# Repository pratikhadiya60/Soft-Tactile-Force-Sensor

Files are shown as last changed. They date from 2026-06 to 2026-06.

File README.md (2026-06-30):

# Soft Tactile Force Sensor

<p align="center">
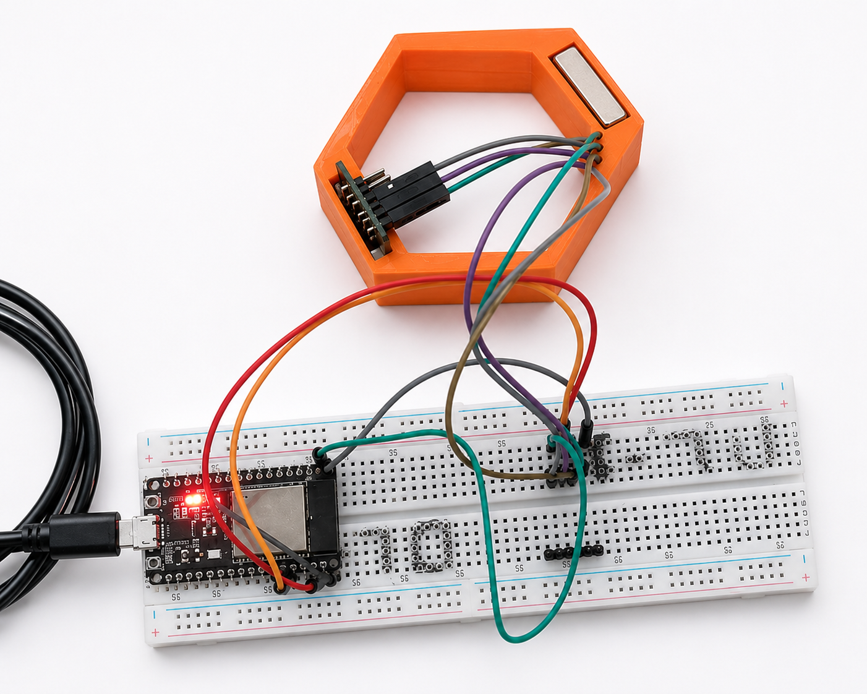
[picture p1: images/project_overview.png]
Prototype Setup
  
</p>

A soft tactile force sensor built using an ESP32 and an MLX90393 magnetometer. The sensor estimates contact force by tracking the movement of a small embedded magnet inside a silicone structure and sends the measurements to a local Flask server over Wi-Fi.

## About the Project

The idea for this project was to estimate contact force without using a traditional load cell.

A small magnet is embedded inside a soft silicone structure while an MLX90393 magnetometer is fixed below it. Whenever force is applied, the silicone compresses and the magnet moves closer to the sensor. This changes the measured magnetic field.

The ESP32 continuously reads the magnetic field values, estimates how much the magnet has moved, and converts that displacement into force using calibration data collected from compression tests. The calculated force is then sent over Wi-Fi to a Flask server where it can be monitored in real time.

This project combines mechanical design, embedded programming, experimental calibration, and basic web-based visualization into a single tactile sensing system.

## How It Works

The sensing principle is fairly simple. Instead of measuring force directly, the sensor measures how much the silicone deforms under an external load.

When force is applied to the top surface, the silicone compresses and the embedded magnet moves closer to the MLX90393 magnetometer. Since the magnetic field strength increases as the distance decreases, the ESP32 can estimate the displacement by monitoring the magnetic field.

The estimated displacement is then converted into force using calibration data collected from compression tests. Finally, the calculated force is sent to a local Flask server where it can be displayed in real time.

## Project Highlights

- Soft silicone based tactile sensing approach
- ESP32 firmware developed using PlatformIO
- MLX90393 3-axis magnetometer for magnetic field measurement
- Experimental force calibration using compression test data
- Real-time force estimation
- Wi-Fi communication with a Flask server
- Complete CAD models, firmware, documentation and calibration data included in this repository

<p align="center">
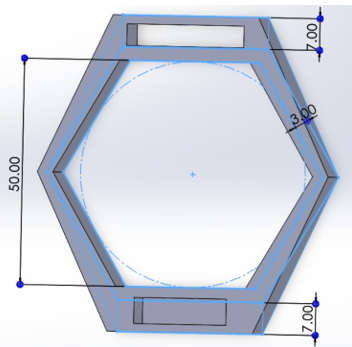
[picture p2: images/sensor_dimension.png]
  
</p>

### Measurement Pipeline

```text
Applied Force
      │
      ▼
Silicone Deformation
      │
      ▼
Magnet Displacement
      │
      ▼
MLX90393 Magnetic Field Measurement
      │
      ▼
ESP32 Processing
      │
      ▼
Displacement Estimation
      │
      ▼
Force Calculation
      │
      ▼
Wi-Fi Data Transmission
      │
      ▼
Flask Server
```

### Force Estimation

The firmware first calibrates the MLX90393 to remove sensor offsets and compensate for the Earth's magnetic field. Once calibration is complete, the magnetic field magnitude is used to estimate the distance between the magnet and the sensor.

The displacement is calculated with respect to the reference position, and a lookup table obtained from experimental testing is used to estimate the corresponding force. Linear interpolation is used between calibration points to improve the resolution of the measurement.

## Repository Structure

The repository is organized so that each part of the project is kept separate. Firmware, CAD files, experimental data, documentation, and hardware files can all be accessed independently.

```text
Soft-Tactile-Force-Sensor
│
├── firmware/      ESP32 firmware (PlatformIO)
├── hardware/      Circuit diagram
├── cad/           3D models of the sensor housing
├── data/          Experimental calibration data
├── docs/          Project report
├── images/        Figures used in this README
├── media/         Project photos and videos
└── server/        Flask server for data visualization
```

## Hardware Used

The prototype was built using commonly available components.

| Component | Description |
|---|---|
| ESP32 DevKit V1 | Main controller |
| MLX90393 | 3-axis magnetometer |
| Neodymium Magnet | Embedded inside the silicone sensor |
| Silicone Structure | Deforms under external force |
| 3D Printed Housing | Holds the sensor and electronics together |

## Circuit Diagram

The ESP32 communicates with the MLX90393 over the I²C interface.

<p align="center">
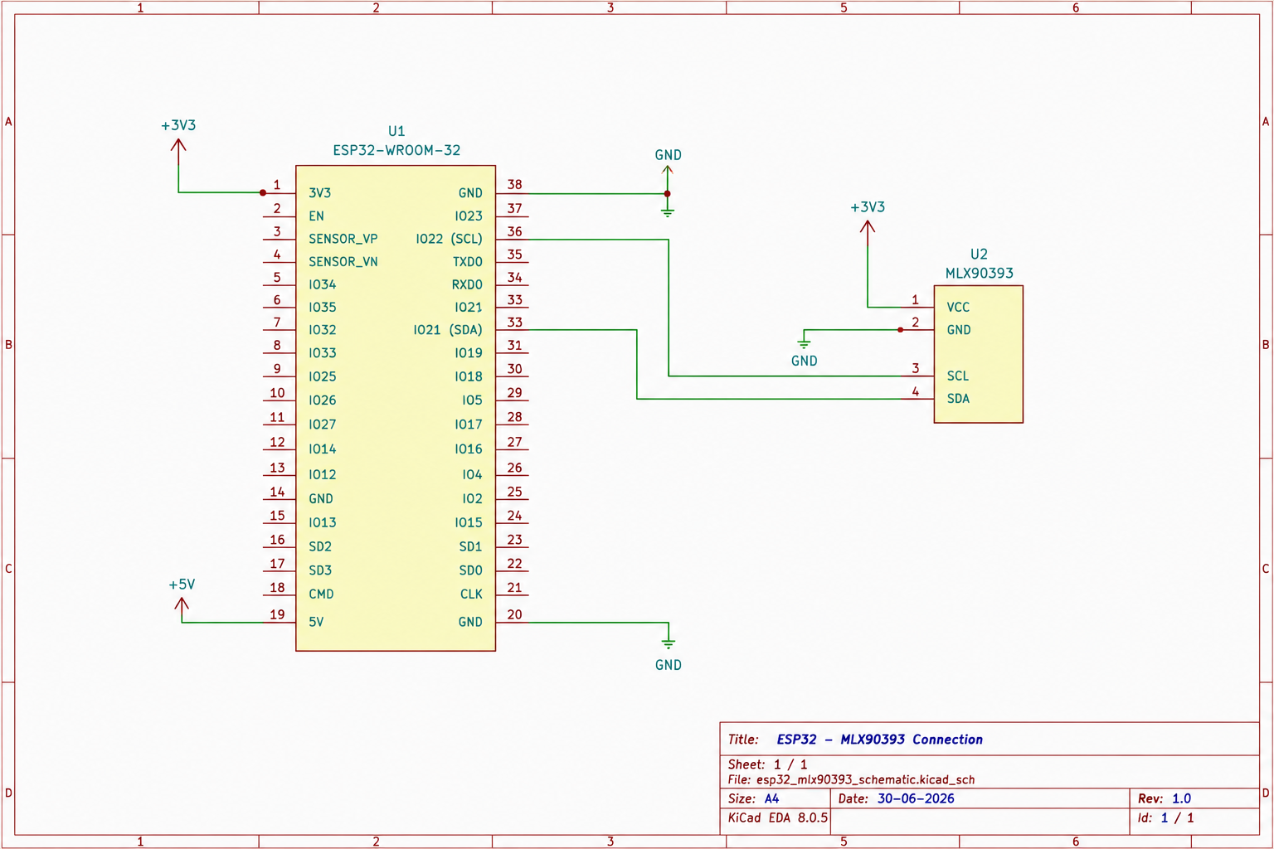
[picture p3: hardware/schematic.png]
  
</p>

| ESP32 | MLX90393 |
|---|---|
| 3.3V | VIN |
| GND | GND |
| GPIO21 | SDA |
| GPIO22 | SCL |

The DRDY and INT pins of the MLX90393 are not used in this project.

## Software

Different parts of the project were developed using different tools.

| Software | Purpose |
|---|---|
| PlatformIO | ESP32 firmware development |
| VS Code | Programming |
| SolidWorks | CAD design |
| COMSOL Multiphysics | Magnetic field simulation |
| Flask | Local server |
| Python | Data visualization |

# Results

The sensor was tested at different stages of development to verify the sensing principle and generate the calibration data used by the firmware.

Instead of estimating force directly from the magnetic field, the system first estimates the displacement of the embedded magnet and then converts that displacement into force using experimentally collected data.

## Magnetic Field vs Distance

The first experiment was performed to study how the magnetic field changes as the distance between the magnet and the MLX90393 sensor changes.

<p align="center">
  
</p>

As expected, the magnetic field increases rapidly when the magnet moves closer to the sensor. This relationship is used by the firmware to estimate the displacement of the magnet during force measurement.

## Magnetic Field Simulation

To better understand the magnetic field distribution around the magnet, a simple COMSOL simulation was performed.

<p align="center">
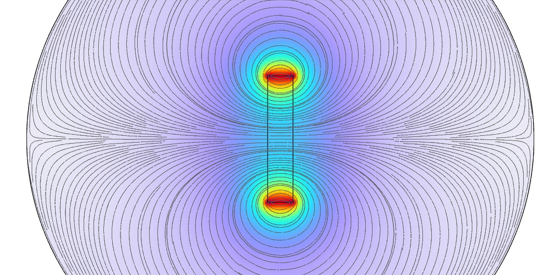
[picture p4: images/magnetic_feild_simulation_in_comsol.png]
  
</p>

The simulation helped visualize the magnetic field around the magnet and confirmed the expected field distribution before building the prototype.

## Compression Test

Compression testing was carried out to obtain the force-displacement data required for calibration.

<p align="center">
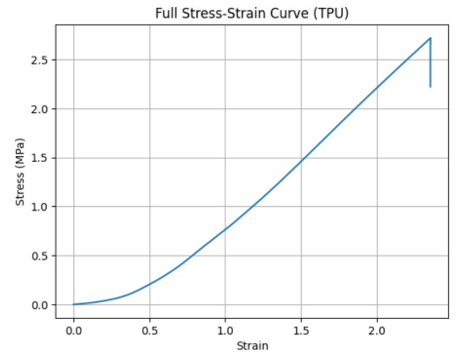
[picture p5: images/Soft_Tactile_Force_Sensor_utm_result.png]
  
</p>

The experimental data obtained from these tests was later converted into a lookup table that is used by the ESP32 firmware for force estimation.

## Force Calibration

The lookup table generated from the compression test is used to convert displacement into force.

<p align="center">
  
</p>

Instead of fitting a mathematical equation, the firmware performs linear interpolation between calibration points. This keeps the implementation simple while closely matching the experimental data.

## Prototype

The final prototype consists of the ESP32 development board, the MLX90393 sensor module, and the 3D printed housing that holds the sensing element.The ESP32 continuously measures the magnetic field, estimates the force, and sends the calculated values to the Flask server over Wi-Fi.

# Getting Started

## Clone the Repository

```bash
git clone https://github.com/pratikhadiya60/Soft-Tactile-Force-Sensor.git
cd Soft-Tactile-Force-Sensor
```

## Firmware

The firmware is developed using **PlatformIO**.

Open the `firmware` folder in VS Code with the PlatformIO extension installed.

Build the project:

```bash
PlatformIO → Build
```

Connect the ESP32 and upload the firmware:

```bash
PlatformIO → Upload
```

Before uploading, update the Wi-Fi credentials and the server IP address in `src/main.cpp`.

## Running the Flask Server

The ESP32 sends force measurements to a local Flask server over Wi-Fi.

Move to the `server` directory and install the required Python packages.

```bash
cd server
pip install -r requirements.txt
python app.py
```

Once the server is running and the ESP32 is connected to the same network, the measured force values will be transmitted automatically.

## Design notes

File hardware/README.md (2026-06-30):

# Hardware

Contains the circuit diagram and hardware documentation.

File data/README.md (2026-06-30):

# Experimental Data

This folder contains the raw experimental datasets used for calibration and validation.

- TPU tensile test
- Compression test
- Force-displacement measurements

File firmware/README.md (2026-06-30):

# Firmware

This folder contains the ESP32 firmware for the Soft Tactile Force Sensor.

## Hardware

- ESP32 DevKit V1
- MLX90393 3-axis magnetometer

## Framework

- PlatformIO
- Arduino Framework

## Libraries

- Adafruit MLX90393 Library

## Build

Open the `firmware` folder in VS Code with PlatformIO and click **Build**.

## Upload

Connect the ESP32 and click **Upload** in PlatformIO.

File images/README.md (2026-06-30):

# Images

This folder contains figures used in the documentation.

- Sensor setup
- Circuit diagram
- COMSOL simulation
- Calibration graph
- UTM results

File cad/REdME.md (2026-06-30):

# CAD Files

This folder contains the CAD model of the magnetometer holder.

Files included:

- `.SLDPRT` - SolidWorks Part
- `.STEP` - Universal CAD model
- `.STL` - 3D printable model

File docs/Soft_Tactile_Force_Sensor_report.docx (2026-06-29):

# Design Lab–1 (ME-205) Project Report

Magnetometer-Based Force Sensing Instrument

Using TPU Hexagonal Structure

Group-C (Section-B)

Team Members:
Hadiya Pratik Ghanshyambhai (2024MEB1347)
Kanav Dumra (2024MEB1356)
Kodepaka Aravind Stalin (2024MEB1361)
Manav Gulati (2024MEB1366)
Pratyush Sahu (2024MEB1373)

Supervised by: Dr. Prabhat K. Agnihotri
LA: Rupinder Singh Mundra
Date: 30 April 2026

Abstract:

This project presents the design and experimental validation of a magnetometer-based force sensing instrument using a flexible hexagonal TPU structure. The system works on the principle that mechanical deformation leads to change in the distance between magnet and magnetometer, which further leads to a change in the magnetic field, which is detected using a magnetometer.

A hexagonal structure was designed and fabricated using Thermoplastic Polyurethane (TPU). A permanent magnet was fixed at one end, while a magnetometer sensor connected to an ESP32 microcontroller was placed at the opposite end. Compression of the structure results in displacement of the magnet, causing measurable variations in magnetic field.

The project involves:

- Calibration of magnetic field vs distance using a Gauss meter
- Measurement of magnetic field variation under deformation
- Mechanical characterization using UTM (Universal Testing Machine)

The results demonstrate a clear relationship between force, deformation, and magnetic field variation, validating the concept of low-cost force sensing.

Introduction:

Force sensing is essential in applications such as robotics, prosthetics, and material testing. Traditional sensors (load cells, strain gauges) can be expensive or rigid. This project explores a flexible and low-cost alternative using:

- Soft material (TPU)
- Magnetic sensing
- Embedded electronics (ESP32)

The working principle is simple:

Applied Force → Deformation → Change in Magnet Distance → Magnetic Field Variation → Electrical Signal

Unlike complex multi-layer metamaterial designs, this project focuses on a single hexagonal unit.

Objectives:

1. To study magnetic field variation with distance To experimentally determine how the magnetic field strength varies with distance from a permanent magnet using a gauss meter, and to establish a calibration curve for further analysis.
2. To simulate magnetic field distribution around a permanent magnet To simulate and analyse the distribution pattern of magnetic field lines around a block magnet
3. To measure magnetic field variation under deformation To analyze how compression of the hexagonal structure affects the distance between the magnet and magnetometer, and to record the resulting changes in magnetic field using an ESP32-based setup.
4. To correlate force, deformation, and magnetic response To develop a relationship between applied force, structural deformation, and corresponding magnetic field variation, thereby demonstrating the working principle of the force sensing mechanism.
5. To validate results using UTM testing To perform mechanical testing using a Universal Testing Machine (UTM) on both a standard TPU specimen and the hexagonal structure.

Theoretical Background:

Force vs Deformation (F–Δx Relationship)

The mechanical behavior of the TPU hexagonal structure can be approximated using Hooke’s Law for elastic materials:

F=k⋅Δx

Where:

- F = Applied force (N)
- k = Effective stiffness of the structure (N/mm)
- Δx = Deformation (mm)

Explanation

- When force is applied, the hexagonal structure compresses
- Initially, the behavior is approximately linear (elastic region)
- The slope of the graph gives stiffness:

k=F/(Δx)

In our Project

- From UTM results:
  - We obtained stress vs strain
  - From that, stiffness can be estimated
- For the hexagon:
  - Stiffness is lower than solid cylinder, which was used earlier for experimentally identifying the Young’s Modulus using ASTM standards.
  - Because of geometric flexibility

Magnetic Field vs Distance

The magnetic field produced by a magnet decreases with distance. For a bar magnet, it approximately follows:

B∝1/(r^n)

Where:

- B = Magnetic field
- r = Distance from magnet
- n≈2 to 3

In our Experiment

- We measured:
  - Magnetic field vs distance (10 cm → 1 cm)
- This serves as calibration data

Magnetic Field vs Deformation (ΔB vs Δx)

When the hexagon compresses:

- Distance decreases:

r=r_0 -Δx

- So the magnetic field becomes:

B=f(r_0 -Δx)

Thus:

ΔB=B(Δx)-B_0

Key Insight

- Small deformation → small increase in B
- Larger deformation → rapid increase in B
- Relationship is non-linear

Force vs Magnetic Field (F–ΔB Relationship)

Combining both relations:

F=k⋅Δx

and

B=f(Δx)

We can write:

F=k⋅f^(-1) (B)

Practical Meaning

- Magnetometer gives magnetic field
- From calibration, we get deformation
- From deformation, we calculate force

Simplified Relation

If small deformation:

ΔB∝Δx

Then:

F∝ΔB

So:

Force is approximately proportional to change in magnetic field (for small deformation range)

COMSOL Simulation:

Simulation of Simple Bar Magnet

Objective

To understand how magnetic field varies with distance from a magnet.

Model Description

- Geometry: Simple bar magnet
- Domain: Air surrounding the magnet
- Physics: Magnetic Fields

Result

- Magnetic field decreases with distance

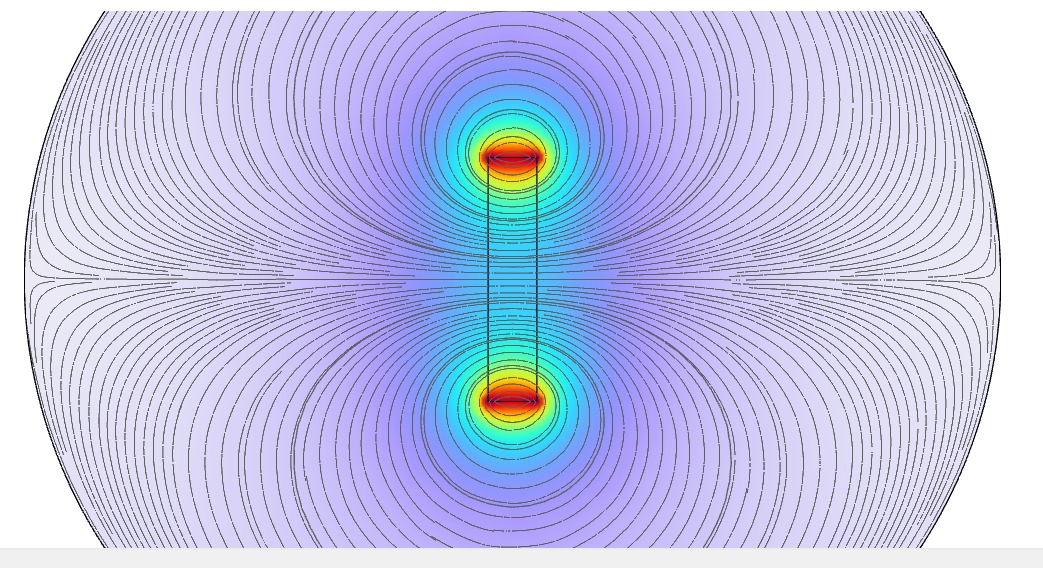
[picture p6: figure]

Conclusion

- Validates the theoretical relation:

B∝1/(r^n)

Working Principle:

The system operates based on the relation between magnetic field and distance.

As the structure compresses:

- Distance between magnet and sensor decreases
- Magnetic field strength increases

This relationship can be approximated as: B∝1/(r^n)

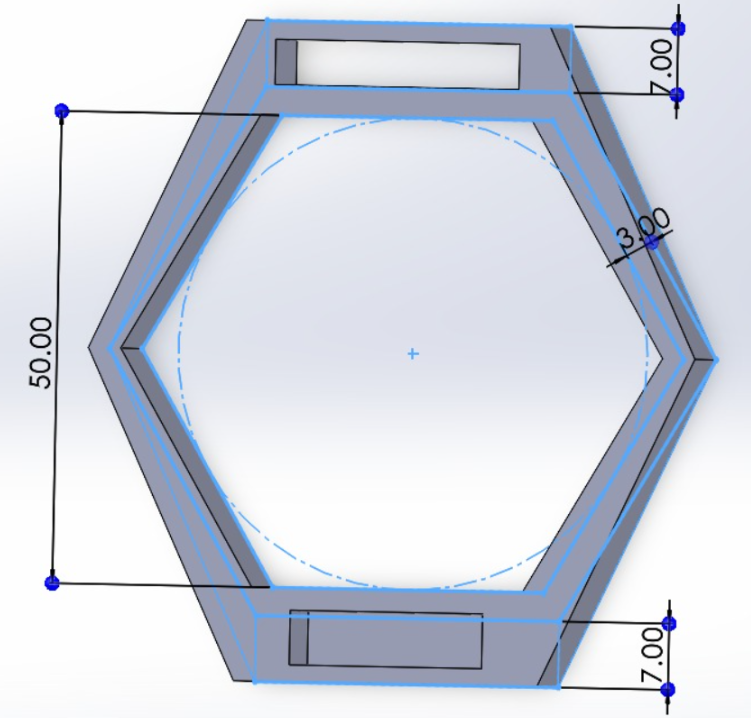
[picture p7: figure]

Design and Fabrication:

CAD Model

- Geometry: Hexagonal structure
- Software used: SolidWorks
- Thickness: 20mm

Material

- Material: Thermoplastic Polyurethane (TPU)
- Properties:
  - Elastic modulus: E≈1.3×10^5 Pa
  - Density: 30 %

Experimental Setup:

Components Used

- Magnetometer: SmartElex MLX90393 Triple Axis Magnetometer (Used to measure the magnetic field variation due to deformation)
- Microcontroller: ESP32 (Used for data acquisition, processing, and real-time output)
- Magnet:
  - Shape: Cubic
  - Size: 1 cm × 1 cm × 1 cm

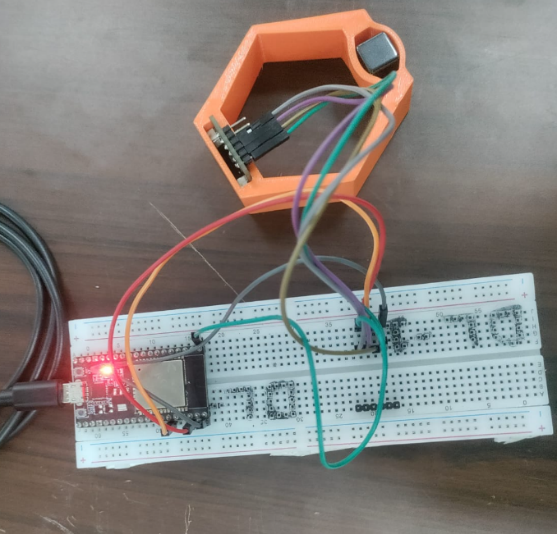
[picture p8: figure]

- Hexagonal Structure:
  - Material: Thermoplastic Polyurethane (TPU)
  - Fabrication method: 3D Printing
- Additional Equipment:
  - Gauss meter (for calibration)
  - Connecting wires and power supply

Setup Description

The experimental setup consists of a flexible hexagonal TPU structure with a magnet and magnetometer placed at opposite ends. The arrangement is designed such that any applied force leads to deformation, which changes the distance between the magnet and the sensor.

- The permanent magnet is rigidly fixed at one end of the hexagonal structure.
- The magnetometer sensor is mounted at the opposite fixed end, ensuring it remains stationary during the experiment.
- The ESP32 microcontroller is connected to the magnetometer to record magnetic field readings in real time and transmit the data to a serial monitor or computer.

Working Configuration

- When no force is applied:
  - The structure remains in its original shape
  - Distance between magnet and sensor is maximum
  - Magnetic field reading is at baseline
- When force is applied:
  - The hexagonal structure compresses
  - Distance between magnet and sensor decreases
  - Magnetic field strength increases

Key Considerations

- Proper alignment of magnet and sensor is maintained to ensure accurate readings
- The structure is compressed along its axis of symmetry
- External disturbances (vibration, misalignment) are minimized

Magnetic Field Calibration:

Objective: To determine the relationship between magnetic field strength and distance from the magnet, which is required for interpreting sensor readings in later experiments.

Procedure

- A Gauss meter was used to measure magnetic field strength.
- The magnet was kept fixed, and the distance between the magnet and probe was varied from 10 cm to 1 cm.
- Readings were recorded at different distances while maintaining proper alignment and minimizing external disturbances.

Observations

Distance (cm) | Magnetic Field (Gauss)
10 cm | 0.1
9 cm | 0.1
8 cm | 0.4
7 cm | 1.0
6 cm | 2.0
5 cm | 4.1
4 cm | 7.7
3 cm | 18.1
2 cm | 52.7
1 cm | 181.2

Result

- The magnetic field increases as the distance decreases.
- The variation is non-linear, with a sharper increase at smaller distances.

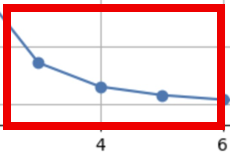
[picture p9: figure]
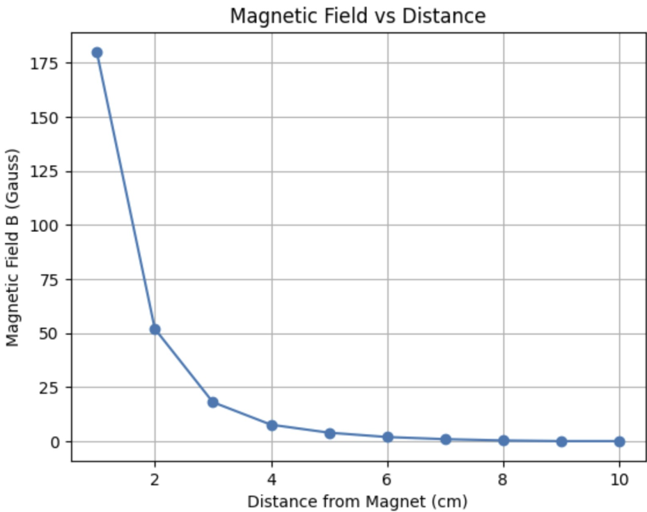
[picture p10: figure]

Compared with the practical graph

Conclusion: The calibration confirms the expected inverse relationship between magnetic field and distance. This serves as a reference for relating magnetic field changes to deformation in the hexagonal structure.

Deformation vs Magnetic Field Experiment:

Objective

To study how mechanical deformation of the hexagonal structure affects the magnetic field, and to establish a relationship between deformation and magnetic field variation.

Procedure

- The fabricated TPU hexagonal structure was placed in a controlled setup.
- The sensor was calibrated in the absence of the magnet.
- At the undeformed state, four different values of the magnetic field were recorded, and the average value was used as the reference value for the undeformed state.
- Compression was applied gradually.
- As the structure compressed, the distance between the magnet and magnetometer decreased.
- The magnetometer readings were recorded in real time using the ESP32 microcontroller.
- Corresponding values of deformation and magnetic field were noted for multiple loading conditions.

Axis Calibration and Vector Correction in 3-Axis Magnetometer

- Introduction: In a 3-axis magnetometer system, the measured magnetic field components (B_x , B_y , B_z ) are affected not only by the external magnetic field but also by sensor misalignment, scaling errors, and cross-axis coupling. During experimentation, it was observed that even when the magnet is moved along a single axis (e.g., X-direction), all three components change. This behavior arises due to the vector nature of the magnetic dipole field and imperfect alignment between the magnet and sensor axes.
- Need for Axis Calibration: Axis calibration is required to ensure that:
- Each axis responds uniformly to the same magnetic field strength
- Cross-axis interference is minimized
- The measured field accurately represents physical motion of the magnet
- Distance estimation based on magnetic field becomes reliable

Without calibration, the sensor output forms an ellipsoidal distortion instead of a spherical response, leading to inaccurate field interpretation.

- Physical Observation of Cross-Axis Coupling: When a magnet is moved along the X-axis, the expected behavior is that only B_x should vary. However, experimentally:
- B_x , B_y , and B_z all change simultaneously
- This occurs because the magnetic field of a bar magnet follows a 3D dipole distribution
- The field at any point depends on position vector (x, y, z) , not independent axes

Thus, axis separation is not perfect in raw sensor data.

- Mathematical Representation: The magnetic field of a dipole is given by:

B(r)=(μ_0)/(4πR^3)[3(m⋅r)r-m]

This implies that:

- Each component B_x ,B_y ,B_z depends on all spatial coordinates
- Movement in one axis inherently affects all three components
- Practical Axis Calibration Method: Instead of relying on theoretical alignment, an experimental calibration approach is used:

Step 1: Data Collection

- Move the magnet in all directions (3D motion)
- Record raw values:

B_x ,B_y ,B_z

Step 2: Hard Iron Correction

Remove constant offset:

B_(offset) =(B_(max) +B_(min))/2

Step 3: Soft Iron Correction

Normalize scaling differences:

B_(scaled) =(B_(corrected))/(Scale factor)

Step 4: Axis Alignment Approximation

Since perfect rotation matrices are complex for this setup, an effective axis is constructed:

B_(aligned) =aB_x +bB_y +cB_z

where a,b,c are experimentally determined weights based on sensitivity.

- Preferred Practical Approach: For this project, instead of relying on individual axis accuracy, the magnetic field magnitude is used:

∣B∣=√(B_x^2 +B_y^2 +B_z^2)

Advantages:

- Independent of sensor orientation
- Eliminates axis misalignment effects
- Provides stable and smooth response
- Suitable for distance estimation models
- Conclusion: Axis calibration improves the reliability of magnetometer readings by correcting offsets, scaling errors, and misalignment effects. However, due to inherent cross-axis coupling in magnetic dipole fields, complete axis separation is not physically achievable. Therefore, the most robust approach for this project is to use vector magnitude ∣B∣ , which provides orientation-independent and stable measurements suitable for distance estimation and force sensing applications.

Observations

Deformation (mm) | Magnetic Field (Gauss)
59.92 | 3.511
57.98 | 3.8756
54.39 | 4.6947
50.46 | 5.8797
46.40 | 7.5637
41.10 | 1.0879
36.54 | 1.5487
31.39 | 2.4432
29.98 | 2.8042
28.94 | 3.1179

Graphical Representation

A graph was plotted between:

- X-axis: Deformation (mm)
- Y-axis: Magnetic Field

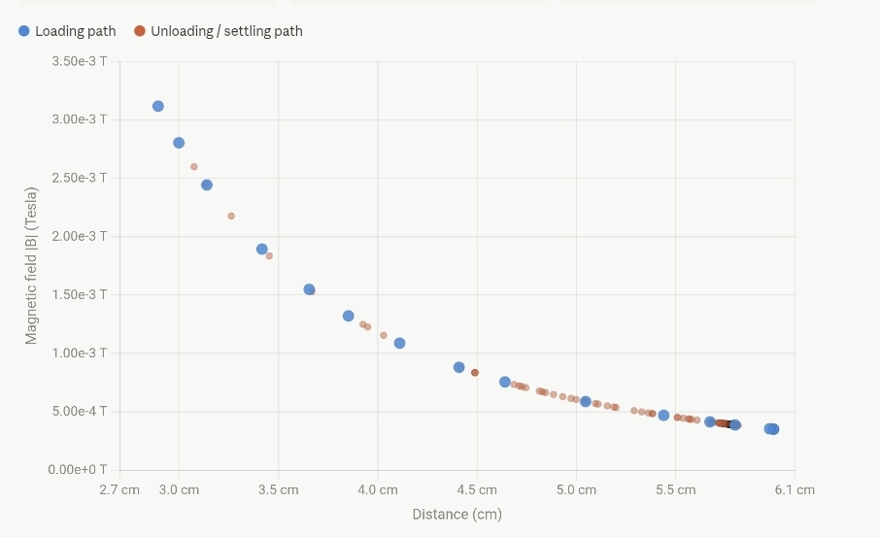
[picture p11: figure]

Results and Analysis

- It was observed that the magnetic field increases with increasing deformation.
- This is because compression reduces the distance between the magnet and sensor.
- The relationship is non-linear, with a steeper increase at higher deformation values.

Key Insight

- Small deformation produces measurable changes in magnetic field
- Sensitivity increases as the magnet comes closer to the sensor

Conclusion

The experiment confirms that deformation of the hexagonal structure leads to a predictable change in magnetic field. This validates the working principle of the system and shows that magnetic field variation can be used to estimate deformation and applied force.

UTM Testing:

Objective: To determine the mechanical properties of TPU material and the hexagonal structure by obtaining their stress–strain behavior, and to relate this behavior to the deformation observed in the force sensing experiment.

TPU Cylindrical Sample

- A standard TPU cylindrical specimen was prepared according to ASTM standards.
- The sample was tested using a Universal Testing Machine (UTM) under compressive loading.

Procedure

- The specimen was placed between the compression plates of the UTM.
- Load was applied gradually, and corresponding deformation was recorded.
- Stress and strain values were calculated from the load and displacement data.

Graph: Stress vs Strain

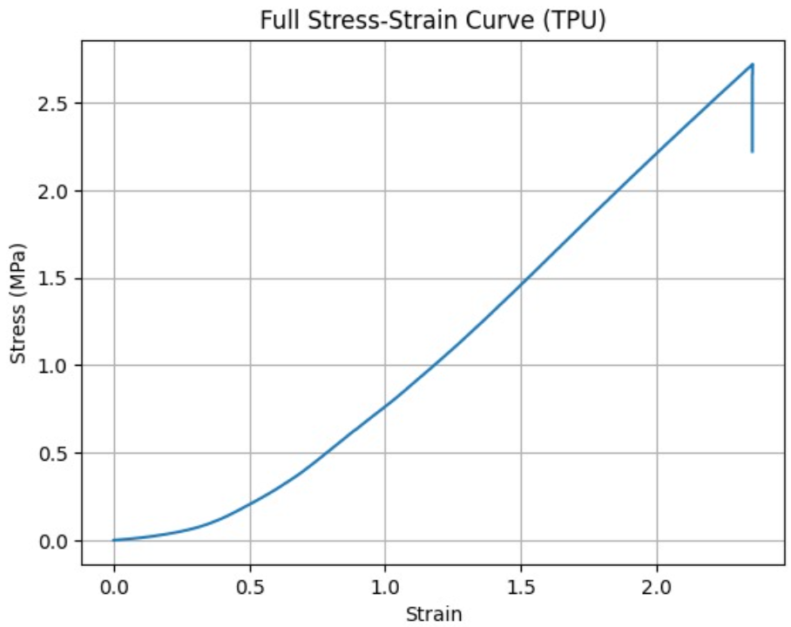
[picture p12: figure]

Young’s Modulus (calculated using the graph): E≈1.3×10^5 Pa

Hexagonal Structure Testing

- The same compression test was performed on the 3D printed hexagonal TPU model.

Procedure

- The hexagonal structure was placed in the UTM.
- Load was applied along its axis of symmetry.
- Deformation and corresponding force were recorded.

Graph:
Force vs Displacement:

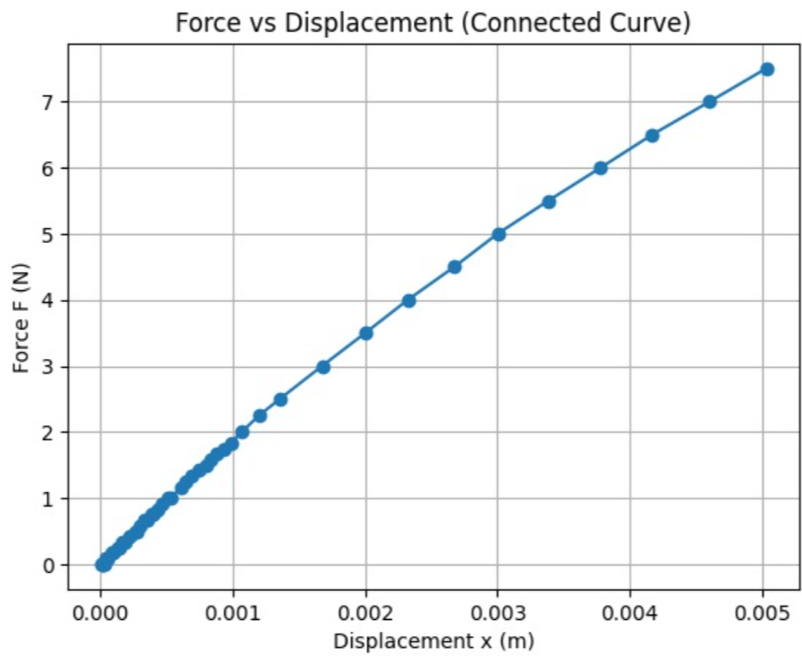
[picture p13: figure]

Stress vs Strain:

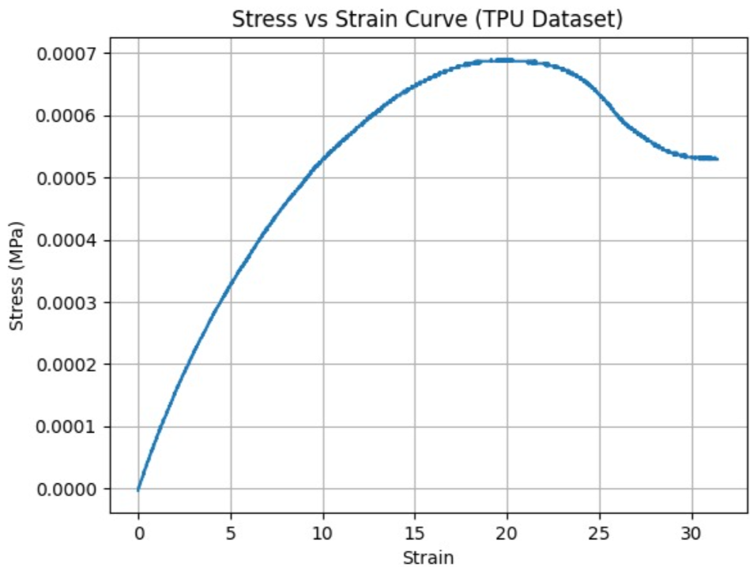
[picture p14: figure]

Equivalent Spring Constant (calculated from the above curve): k≈1500 N.m^(-1)

Results and Comparison

- The TPU cylindrical sample showed a relatively uniform and predictable stress–strain curve, representing the base material behavior.
- The hexagonal structure exhibited:
  - Lower stiffness
  - Higher deformation for the same load
  - Non-linear behavior due to geometry

Key Insight

- The difference in behavior confirms that:

Geometry plays a major role in flexibility and deformation, not just material properties.

Conclusion

UTM testing successfully provided the mechanical characterization of both the material and the structure. The results help in understanding how applied force leads to deformation, which is essential for correlating force with magnetic field variation in the sensing system.

Results and Discussion:

The experimental study provides a clear relationship between mechanical deformation and magnetic field variation. The system demonstrates that even small compressive forces applied to the TPU structure lead to measurable changes in magnetic field intensity.

Magnetic Field vs Distance Behavior

The calibration results confirm that magnetic field strength increases sharply as the distance between magnet and sensor decreases. The observed trend follows a non-linear inverse relationship, consistent with theoretical dipole field behavior.

Key observations:

- Strong sensitivity at small distances (< 5 cm)
- Gradual flattening of response at higher distances

Deformation Response

Under compression, the hexagonal TPU structure behaves elastically within the tested range. The deformation causes a proportional increase in magnetic field reading.

Important findings:

- Initial region shows near-linear response between deformation and magnetic field
- At higher compression, slight non-linearity appears due to geometric instability

Force–Magnetic Coupling

By combining UTM data with sensor output, a coupled relationship between force and magnetic field can be established. This enables indirect force sensing using only magnetic measurements.

Difficulties Faced During Experiment:

During the execution of the project, several practical challenges were encountered:

Alignment Issues: Maintaining perfect alignment between magnet and magnetometer was difficult. Even small angular misalignment caused fluctuations in readings.

Manual Loading Errors: Force was applied manually in initial trials, leading to inconsistent deformation rates and non-uniform data points.

Sensor Noise: The magnetometer readings showed minor fluctuations due to electromagnetic interference and ESP32 ADC noise.

Calibration Limitations: Limited access to precision gauss meter reduced the resolution of magnetic field calibration.

Weekly Progress Report (8 Weeks):

Week 1

- Literature review on magnetometer-based sensing
- Initial concept development

Week 2

- CAD design of hexagonal TPU structure
- Selection of material and magnet

Week 3

- Simulation of magnetic field distribution (COMSOL basic model)
- Refinement of geometry

Week 4

- TPU 3D printing and prototype fabrication
- Basic assembly of magnet and sensor setup

Week 5

- ESP32 programming and sensor interfacing
- Initial data acquisition tests

Week 6

- Magnetic field vs distance calibration experiments
- Data logging improvements

Week 7

- UTM testing of TPU samples
- Force vs deformation data collection

Week 8

- Final integration of all datasets
- Graph plotting, analysis, and report preparation

Future Scope:

Stackable Integrated Model (Helmet Application)

A major extension of this work is the development of a stacked multi-layer sensing system, where multiple hexagonal TPU units of small size are integrated vertically and embedded into a wearable structure such as a helmet.

Concept:

- Each hexagonal unit acts as an individual force sensor
- Multiple units stacked to form a 3D sensing grid
- Entire structure embedded inside protective gear

Helmet-Based Application:

- Impact detection in helmets
- Crash force mapping in real time
- Directional force sensing (front, side, top impacts)

Improvements

- Replace a single magnet with calibrated magnetic arrays
- Use digital force actuators for controlled testing
- Improve sensor fusion using multiple magnetometers
- Wireless data transmission system

Applications:

- Soft robotics
- Wearable force sensing systems
- Helmet impact detection systems

Conclusion:

The project successfully demonstrates a low-cost and flexible force sensing system using a TPU hexagonal structure and magnetometer-based detection. The results validate that mechanical deformation can be effectively translated into measurable magnetic field variations, establishing a clear coupling between applied force, structural deformation, and magnetic response.

The experimental observations from both calibration and deformation testing confirm that the system is capable of capturing consistent trends, particularly in the low to moderate force range. Despite minor experimental limitations such as alignment errors and sensor noise, the overall behavior remains stable and repeatable, making the concept viable for practical sensing applications.

Furthermore, the integration of ESP32 for data acquisition proves that real-time monitoring is feasible with low-cost embedded systems. The project also highlights the potential of soft materials like TPU in developing compliant sensing structures that can replace or complement traditional rigid sensors.

The system shows strong potential for future development into wearable and stacked sensing architectures, particularly for safety and biomedical applications.

References:

1. ASTM standards for TPU testing
2. ESP32 technical documentation
3. Research papers on magnetic sensing in soft robotics

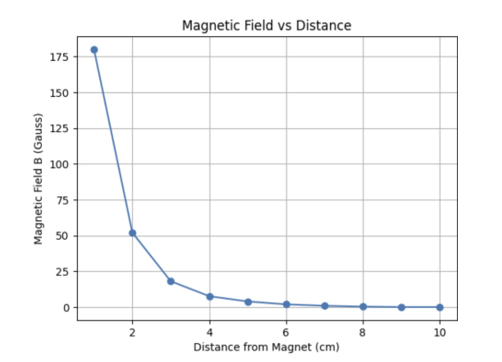
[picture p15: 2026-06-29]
images/practical_magnetic _value_graph.png

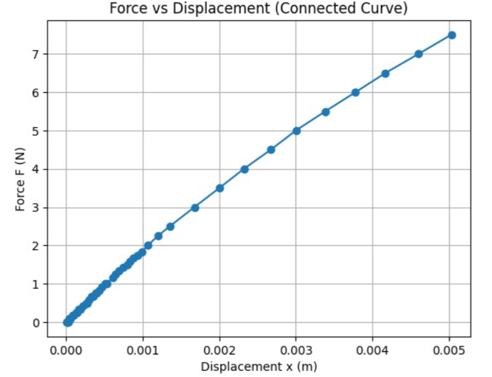
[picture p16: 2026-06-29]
images/sensor_force_vs_distace _graph.png

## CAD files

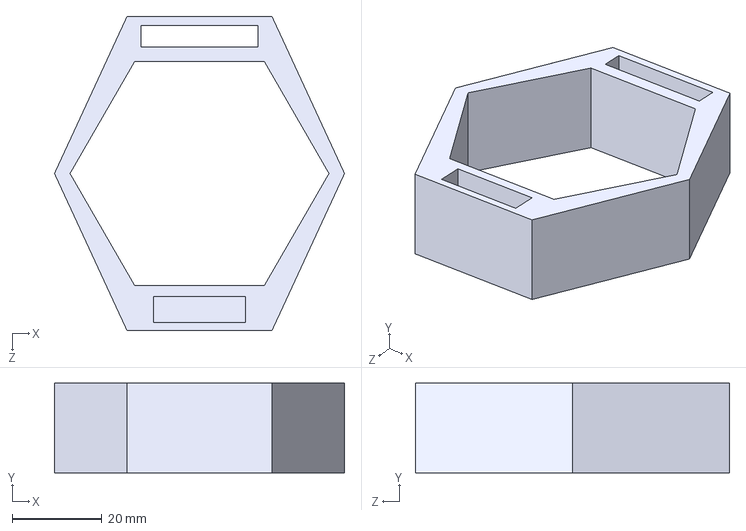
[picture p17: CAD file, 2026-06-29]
cad/megnetometer holder.STEP
64.7 x 20.0 x 70.0 mm

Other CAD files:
cad/megnetometer_holder.SLDPRT
cad/megnetometer_holder.STL

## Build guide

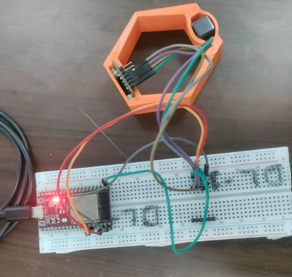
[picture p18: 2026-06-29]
images/sensor_setup.png

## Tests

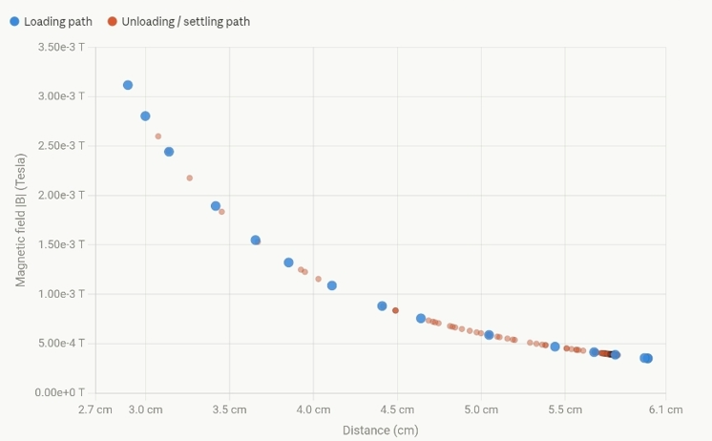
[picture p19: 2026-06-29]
images/calibrated_magnetometer_magnetic_values_graph.png

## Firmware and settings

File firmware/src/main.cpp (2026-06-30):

#include <Arduino.h>
#include <Wire.h>
#include <Adafruit_MLX90393.h>
#include <WiFi.h>
#include <HTTPClient.h>
Adafruit_MLX90393 sensor = Adafruit_MLX90393();

const char* ssid = "YOUR_WIFI_SSID";
const char* password = "YOUR_WIFI_PASSWORD";
const char* serverUrl = "http://<SERVER_IP>:5000/data";
// Raw values
float x, y, z;

// Hard iron (offset)
float x_offset = 0, y_offset = 0, z_offset = 0;

// Soft iron (scale)
float x_scale = 1, y_scale = 1, z_scale = 1;

// Earth field
float x_earth = 0, y_earth = 0, z_earth = 0;

//for distance calculation   
float R_ref = 60;   
float B_ref = 0;              // will be set after placing magnet
bool magnetCalibrated = false;

// Min/Max for calibration
float x_min = 9999, x_max = -9999;
float y_min = 9999, y_max = -9999;
float z_min = 9999, z_max = -9999;

// for smothning values 

bool calibrated = false;

// ===== FORCE TABLE =====
const int n = 32;

float disp[n] = { 0, 1, 2, 3, 4, 5, 6, 7, 8, 9, 10, 11, 12, 13, 14, 15, 16, 17, 18, 19, 20, 21, 22, 23, 24, 25, 26, 27, 28, 29, 30, 31 };

float force[n] = { 0, 1.833, 3.5, 5, 6.25, 7.41667, 8.5, 9.5, 10.4167, 11.1667, 12, 12.6667, 13.25, 13.75, 14.25, 14.75, 15, 15.3333, 15.5, 15.5833, 15.5833, 15.5833, 15.5, 15.33, 15, 14.33, 13.5833, 13, 12.5, 12.25, 12.0833, 12 };

// ===== INTERPOLATION FUNCTION =====
float getForce(float x) {

  if (x <= disp[0]) return force[0];
    if (x >= disp[n-1]) return force[n-1];

  for (int i = 0; i < n-1; i++) {
    if (x >= disp[i] && x <= disp[i+1]) {

      float x1 = disp[i];
      float x2 = disp[i+1];
      float y1 = force[i];
      float y2 = force[i+1];

      return y1 + (y2 - y1) * (x - x1) / (x2 - x1);
    }
  }
  return 0;
}

void setup() {
  Serial.begin(115200);
  Wire.begin();


  WiFi.begin(ssid, password);
  Serial.print("Connecting to WiFi");

  while (WiFi.status() != WL_CONNECTED) {
    delay(1000);
    Serial.print(".");
  }

  Serial.println("\nConnected!");
  Serial.print("ESP32 IP: ");
  Serial.println(WiFi.localIP());

  if (!sensor.begin_I2C()) {
    Serial.println("Sensor not found!");
    while (1);
  }

  Serial.println("=== FULL CALIBRATION MODE ===");
  Serial.println("Rotate sensor in all directions...");
  Serial.println("Press 'f' when done.");
  Serial.println("Place magnet at 60mm and press 'm' to calibrate reference");
}

void loop() {

  if (!sensor.readData(&x, &y, &z)) return;
  char cmd = 0;

    if (Serial.available()) {
      cmd = Serial.read();

      // ignore newline / carriage return
      if (cmd == '\n' || cmd == '\r') cmd = 0;

      if (cmd != 0) {
        Serial.print("Received: ");
        Serial.println(cmd);
      }
    }



  // -------------------------
  // STEP 1: Collect Min/Max
  // -------------------------
  if (!calibrated) {
    x_min = min(x_min, x);
    x_max = max(x_max, x);

    y_min = min(y_min, y);
    y_max = max(y_max, y);

    z_min = min(z_min, z);
    z_max = max(z_max, z);

    Serial.print("Calibrating... X:");
    Serial.print(x);
    Serial.print(" Y:");
    Serial.print(y);
    Serial.print(" Z:");
    Serial.println(z);


    if (cmd == 'f') {
      // HARD IRON OFFSET
      x_offset = (x_max + x_min) / 2;
      y_offset = (y_max + y_min) / 2;
      z_offset = (z_max + z_min) / 2;

      // SOFT IRON SCALE
      float x_range = (x_max - x_min) / 2;
      float y_range = (y_max - y_min) / 2;
      float z_range = (z_max - z_min) / 2;

      float avg_range = (x_range + y_range + z_range) / 3;

      x_scale = avg_range / x_range;
      y_scale = avg_range / y_range;
      z_scale = avg_range / z_range;

      calibrated = true;

      Serial.println("Calibration DONE!");
      Serial.println("Now keep sensor fixed and press 'e' for Earth field");
    }

    delay(100);
    return;
  }

  // -------------------------
  // STEP 2: Apply Calibration
  // -------------------------
  float x_corr = (x - x_offset) * x_scale;
  float y_corr = (y - y_offset) * y_scale;
  float z_corr = (z - z_offset) * z_scale;

  // -------------------------
  // STEP 3: Earth Field Capture
  // -------------------------

  if (cmd == 'e') {
    x_earth = x_corr;
    y_earth = y_corr;
    z_earth = z_corr;

    Serial.println("Earth field captured!");
  }

  // -------------------------
  // STEP 4: Remove Earth Field
  // -------------------------
  float x_final = x_corr - x_earth;
  float y_final = y_corr - y_earth;
  float z_final = z_corr - z_earth;

  // Magnitude
  float B = sqrt(x_final*x_final + y_final*y_final + z_final*z_final);

  // ===== MAGNET REFERENCE CALIBRATION =====
  if (!magnetCalibrated) {

    if (cmd == 'm') {
      B_ref = B;
      magnetCalibrated = true;

      Serial.print("B_ref set to: ");
      Serial.println(B_ref);
      Serial.println("Starting measurement...");
    }

    Serial.print("Waiting for magnet calibration... B = ");
    Serial.println(B);

    delay(200);
    return;   // STOP further calculations until calibrated
  }


  if (B > 1) {

    // Distance from magnetometer
    float R = R_ref * pow((B_ref / B), 1.0/3.0);

    // Displacement (movement toward sensor)
    float displacement = R_ref - R;

    // Safety clamp
    if (displacement < 0) displacement = 0;

    // Limit to table range (VERY IMPORTANT)
    if (displacement > 31.0) displacement = 31.0;

    // Force from table
    float F = getForce(displacement);
    if (WiFi.status() == WL_CONNECTED) {
      HTTPClient http;

      http.begin(serverUrl);
      http.addHeader("Content-Type", "application/json");

      String json = "{";
      json += "\"B\":" + String(B) + ",";
      json += "\"r\":" + String(displacement) + ",";
      json += "\"F\":" + String(F);
      json += "}";

      int response = http.POST(json);

      Serial.print("Sent: ");
      Serial.println(json);

      Serial.print("Response: ");
      Serial.println(response);

      http.end();
    }

    // Output
    Serial.print("Distance(mm): "); Serial.print(R);
    Serial.print("  Displacement(mm): "); Serial.print(displacement);
    Serial.print("  Force(N): "); Serial.println(F);
  }

  // -------------------------
  // OUTPUT
  // -------------------------
  // Serial.print("X: "); Serial.print(x_final);
  // Serial.print(" Y: "); Serial.print(y_final);
  // Serial.print(" Z: "); Serial.print(z_final);
  Serial.print(" |B|: "); Serial.println(B);

  delay(200);
}

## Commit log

2026-06-29 upload most of the files of project on github
    [hollow_comp.csv, megnetometer holder.STEP, megnetometer_holder.SLDPRT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]
2026-06-30 prototype section photo removed because of the quality
